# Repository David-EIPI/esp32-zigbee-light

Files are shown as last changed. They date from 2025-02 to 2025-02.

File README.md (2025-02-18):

# esp32-zigbee-light
Remotely controlled indoor light powered by ESP32-H2, integrated with Zigbee and Home Assistant.

## Overview
Building the [stm32-zigbee-light project](https://github.com/David-EIPI/stm32-zigbee-light) left me with several spare PCBs. I decided to repurpose them to experiment with Espressif's Zigbee SDK (zSDK). Overall, zSDK is similar to STM's Z-Stack. Programming with zSDK seems to require slightly fewer API calls, though Z-Stack is somewhat better documented.

## Firmware
The project is written in C and built using `idf.py`. It implements a zero-crossing detector for TRIAC-based dimming and supports the **HLK-LD2420S** mmWave motion sensor with adjustable sensing distance. The firmware exposes 6 endpoints and 11 clusters:

- **6 Analog Output clusters** (configuration)
- **1 Analog Input cluster** (detected presence distance)
- **2 Binary Input clusters** (motion state, light state)
- **1 Multistate Value cluster** (operation mode)
- **1 OnOff cluster** (dimming enable control)

### Motion Sensor
The **HiLink LD2420S** is an **mmWave motion sensor** (not a presence sensor). It is more sensitive than traditional PIR sensors and can estimate the approximate distance to a moving object, in addition to detecting motion.

Communication with the sensor is achieved through a standard text-based UART interface. The sensor can be configured with various parameters such as sensitivity, distance range, scanning frequency, etc. This configuration must be done individually for each sensor using the manufacturer's proprietary software. The serial communication protocol is available on the manufacturer's website, but the documentation is brief and somewhat difficult to interpret.

Rather than configuring the sensor internally, I opted to parse its output. The output contains information about both motion detection and the estimated distance to the detected object. In the firmware, this distance is compared against a configurable threshold to trigger a motion detection event. The threshold is adjustable via Zigbee, providing a practical way to control the sensor's sensitivity.

The sensor is powered through a transistor switch, allowing the firmware to power-cycle it when necessary. I used a **PNP** transistor, which proved to be a suboptimal choice. The sensor draws relatively high current (~50-60mA) and is sensitive to supply voltage. Below **3.2V**, it becomes unstable, and its distance measurements become unreliable. Therefore, the transistor base current needs to be sufficiently high to minimize the voltage drop across it to less than **0.1V**. 
A MOSFET would certainly be a more suitable as a switch here.

## Hardware
I re-used the PCB from the [stm32-zigbee-light](https://github.com/David-EIPI/stm32-zigbee-light) project as the power supply and as the base for the TRIAC dimming circuit. Only a few minor modifications were necessary to integrate the **LD2420S** motion sensor.

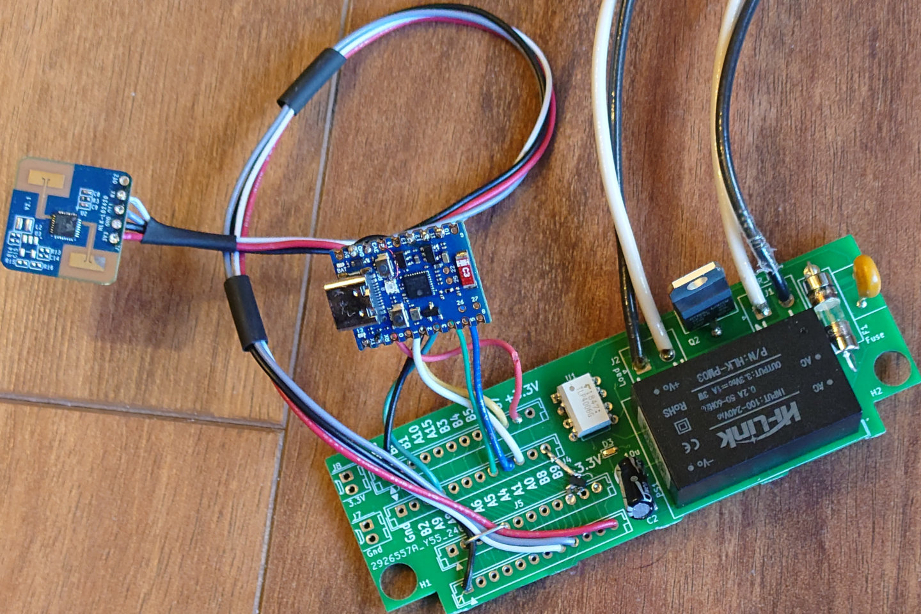
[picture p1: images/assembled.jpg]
The assembled board.
  
Assembled board.

The control board is based on the **ESP32-H2**. I used a small module called the **ESP32-H2 Super Mini**, designed by **Tenstar Robot**. Despite its compact size, the board provides plenty of accessible GPIOs and works well, with **one exception** that I will describe below. This power-on issue is likely to happen in other circuits with a similar power source.

When powered via **USB**, the **ESP32-H2** boots normally. However, when powered from AC mains via the HiLink AC-DC converter, it fails to start. 

I suspect that the HiLink adapter's output capacitor has a high capacitance, leading to a slow output voltage rise **(low slew rate)**, which interferes with the ESP32-H2 startup sequence.

#### Solution:
I added a **4.7µF capacitor** to the **Enable (EN)** pin to delay the startup, which resolved the issue. The module now boots reliably every time. 

Other capacitor values might work as well, but I did not experiment further.

The board is densely packed, leaving little room for additional components. Furthermore, the **EN pin** is not routed to any easily accessible pad. I managed to solder a **0603** capacitor next to the reset button, but to me this was a fairly tricky soldering task.

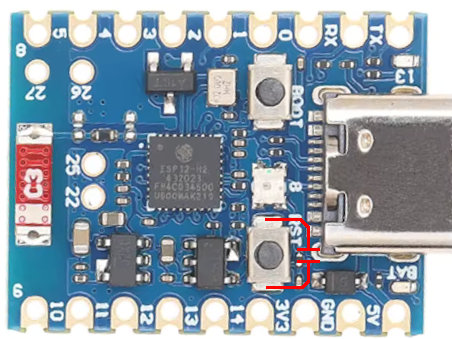
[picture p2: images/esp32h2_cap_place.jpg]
Capacitor placement
  
Capacitor placement is indicated by red lines.

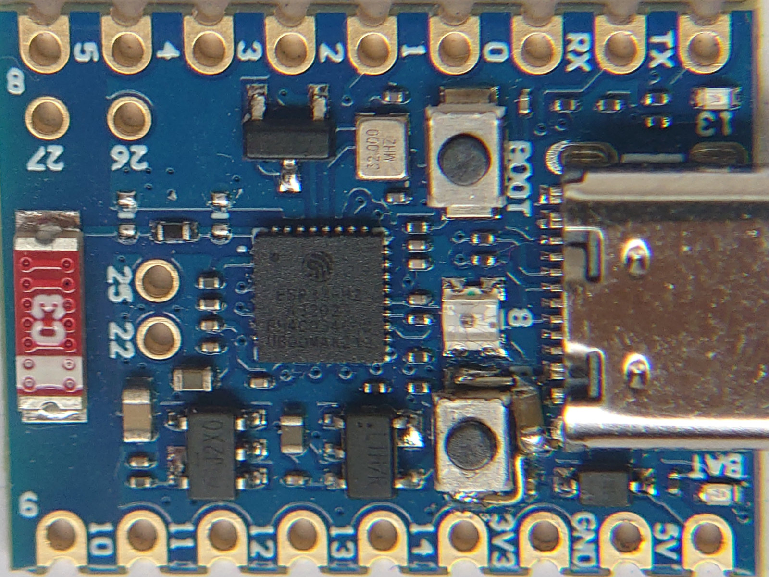
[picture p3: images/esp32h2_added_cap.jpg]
Capacitor photo
  
Photo of the actual board with the added **4.7µF** capacitor.

## ZHA Quirk
As of now, **ZHA (Zigbee Home Automation)** does not fully support several standard Zigbee clusters required for this project, including:

- **Analog Input cluster**
- **Binary Input cluster**
- **Multistate Value cluster**

Additionally, **present_value** atribute of **Multistate Value** cluster is incorrectly defined as **Float32** instead of **uint16** in the underlying **zigpy** library.

Until these clusters are officially supported in the main **ZHA** integration, a custom **quirk** script is required. This quirk file provides proper cluster handling and also extends supported units for the **Analog Input** cluster, adding **microseconds** as a unit. This is useful for the **Phase Correction** setting in the dimming control.

The quirk file should be placed in Home Assistant configuration directory under custom_zha_quirks.
You may need to restart ZHA integration or Home Assistant for the changes to take effect.

The screenshot below shows the device page with custom entity names:

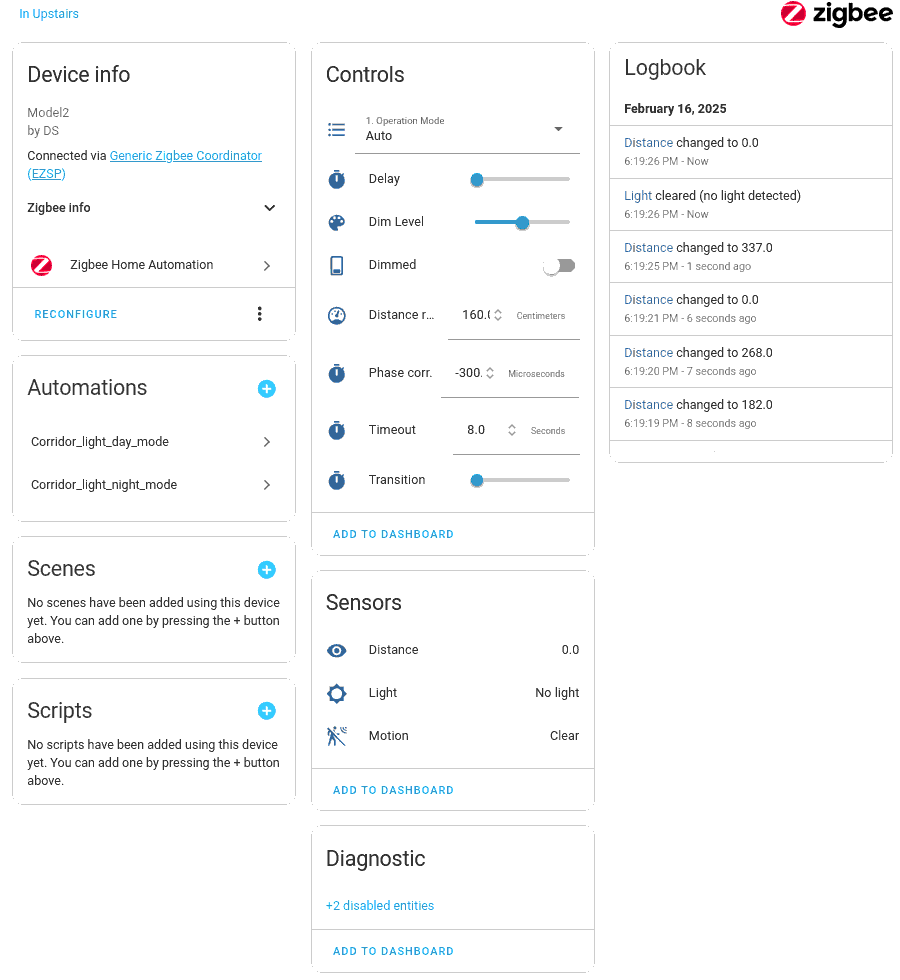
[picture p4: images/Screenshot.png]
Device page
  
ZHA device page in Home Assistant.

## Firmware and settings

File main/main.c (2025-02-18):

/*
 * SPDX-FileCopyrightText: 2021-2024 Espressif Systems (Shanghai) CO LTD
 *
 * SPDX-License-Identifier: CC0-1.0
 *
 * Zigbee HA_on_off_light Example
 *
 * This example code is in the Public Domain (or CC0 licensed, at your option.)
 *
 * Unless required by applicable law or agreed to in writing, this
 * software is distributed on an "AS IS" BASIS, WITHOUT WARRANTIES OR
 * CONDITIONS OF ANY KIND, either express or implied.
 */

#include "freertos/FreeRTOS.h"
#include "freertos/task.h"
#include "esp_check.h"
#include "esp_zigbee_core.h"
#include "esp_log.h"
#include "nvs_flash.h"
#include "ha/esp_zigbee_ha_standard.h"
#include "driver/gpio.h"
#include "main.h"
#include "clock.h"
#include "ld2420_comm.h"
#include "triac_dimmer.h"

#if !defined ZB_ED_ROLE
#error Define ZB_ED_ROLE in idf.py menuconfig to compile light (End Device) source code.
#endif

static const char *TAG = "APP_MAIN";



enum _operation_modes {
    OPMODE_AUTO = 1,
    OPMODE_ON = 2,
    OPMODE_OFF = 3,
};

static uint16_t operation_mode = OPMODE_AUTO;
static bool enable_dimmed_mode = false;
static int prev_motion_detected = 0;
static int light_state = 1, prev_light_state = 0;
static int32_t light_delay = 2; // seconds, delay after motion detection
static int32_t light_timeout = 10; // seconds, time to keep the light on after motion has stopped
static int32_t light_dim_level = DIM_LEVEL_MAX/2;

static uint64_t light_time_on = 0;
static uint64_t no_motion_time = 0;
static gptimer_handle_t timer = 0;
static const uint32_t timer_resolution = 10 * 1000;

static const unsigned indication_led_pin = 13;

TaskHandle_t dimmerTaskHandle = NULL;

/********************* Define functions **************************/
static void bdb_start_top_level_commissioning_cb(uint8_t mode_mask)
{
    ESP_ERROR_CHECK(esp_zb_bdb_start_top_level_commissioning(mode_mask));
}

static const int ZB_INIT_FAIL_COUNT_TO_REBOOT = 60;
static const int ZB_ZDO_FAIL_COUNT_TO_REBOOT = 10;
static int zb_fail_count = 0;


static struct {
    char     description[16];
    float    min_present;
    float    max_present;
    float    present_value;
    float    resolution;
    uint16_t status_flags;
    uint16_t units;
    uint32_t app_type;
    volatile int32_t *value_ptr;
    char     nvs_key[8];
} analog_attr_values[] = {
    {
    .description = "\x07" "Timeout",
    .min_present = 1,
    .max_present = 3600,
    .present_value = 20,
    .resolution = 1,
    .status_flags = 0,
    .units = 73, /* 73 = seconds */
    .app_type = 14 << 16, /* 14 = timer */
//    .value_ptr = &motionTimeout,
    .value_ptr = &light_timeout,
    .nvs_key = "AO_00",
    },

    {
    .description = "\x05" "Delay",
    .min_present = 0,
    .max_present = 20,
    .present_value = 2,
    .resolution = 1,
    .status_flags = 0,
    .units = 73, /* 73 = seconds */
    .app_type = 14 << 16, /* 14 = timer */
    .value_ptr = &light_delay,
    .nvs_key = "AO_01",
    },

    {
    .description = "\x0e" "Distance range",
    .min_present = 1,
    .max_present = 1000,
    .present_value = 200,
    .resolution = 1,
    .status_flags = 0,
    .units = 118, /* 118 = cm */
    .app_type = 2 << 16, /* 2 = Gauge */
    .value_ptr = &motionThreshold,
    .nvs_key = "AO_02",
    },

    {
    .description = "\x09" "Dim level",
    .min_present = 0,
    .max_present = 100,
    .present_value = 50,
    .resolution = 1,
    .status_flags = 0,
    .units = 98, /* 98 = % */
    .app_type = 15 << 16, /* 15 = palette */
    .value_ptr = &light_dim_level,
    .nvs_key = "AO_03",
    },

    {
    .description = "\x0b" "Phase corr.",
    .min_present = -10000,
    .max_present = 10000,
    .present_value = 0,
    .resolution = 1,
    .status_flags = 0,
    .units = 194, /* 194 = microseconds */
    .app_type = 14 << 16, /* 15 = timer */
    .value_ptr = &phaseCorrection_us,
    .nvs_key = "AO_04",
    },

    {
    .description = "\x0a" "Transition",
    .min_present = 0,
    .max_present = 15,
    .present_value = 0,
    .resolution = 1,
    .status_flags = 0,
    .units = 95,
    .app_type = 14 << 16, /* 15 = timer */
    .value_ptr = &transitionTime,
    .nvs_key = "AO_05",
    },


};



static struct {
    char     *states_text;
    char     description[16];
    uint16_t *present_value_ptr;
    uint16_t status_flags;
    uint16_t number_of_states;
    char     nvs_key[8];
} multistate_attr_values[] = {
    {

/* Binary format for the ZCL string array: 1. type; 2. count; 3. array of strings.
*/
    .states_text = "\x42"       /*ESP_ZB_ZCL_ATTR_TYPE_CHAR_STRING = 0x42 */
                    "\x04\x00"  /* Element count */
                    "\x04" "Auto"
                    "\x02" "On"
                    "\x03" "Off",
    .description = "\x0e" "Operation mode",
    .present_value_ptr = &operation_mode,
    .status_flags = 0,
    .number_of_states = 3,
    .nvs_key = "MV_00",
    }
};

char light_on_binary_desc[] = "\x0b" "Light is on";
char motion_binary_desc[] = "\x0f" "Motion detected";

const char ZB_STORAGE_NAMESPACE[] = "zb_storage";

static void init_gpio(void)
{
    const gpio_config_t io_conf = {
        .intr_type = GPIO_INTR_DISABLE,
        .mode = GPIO_MODE_OUTPUT,
        .pin_bit_mask = (1ULL << indication_led_pin),
        .pull_down_en = 0,
        .pull_up_en = 0,
    };

    gpio_config(&io_conf);
    gpio_set_level(indication_led_pin, 1);
}

/* Signal the dimmer task to disable its sync source and stop the timer
    to avoid light flash when the source pin is disabled at restart. */
static void stop_dimmer_and_restart(void)
{
    stopDimmer = 1;
    vTaskDelay(pdMS_TO_TICKS(200));
    esp_restart();
}


void esp_zb_app_signal_handler(esp_zb_app_signal_t *signal_struct)
{
    uint32_t *p_sg_p       = signal_struct->p_app_signal;
    esp_err_t err_status = signal_struct->esp_err_status;
    esp_zb_app_signal_type_t sig_type = *p_sg_p;
    uint8_t min_lqi;

    switch (sig_type) {
    case ESP_ZB_NLME_STATUS_INDICATION:
        ESP_LOGI(TAG, "%s, status: 0x%x\n", esp_zb_zdo_signal_to_string(sig_type), *(uint8_t *)esp_zb_app_signal_get_params(p_sg_p));
        break;
    case ESP_ZB_ZDO_SIGNAL_SKIP_STARTUP:
        ESP_LOGI(TAG, "Zigbee stack initialized");
        esp_zb_bdb_start_top_level_commissioning(ESP_ZB_BDB_MODE_INITIALIZATION);
        min_lqi = esp_zb_secur_network_min_join_lqi_get();
        ESP_LOGI(TAG, "Min LQI = %u", (unsigned)min_lqi);
        esp_zb_secur_network_min_join_lqi_set(0);
        break;
    case ESP_ZB_BDB_SIGNAL_DEVICE_FIRST_START:
    case ESP_ZB_BDB_SIGNAL_DEVICE_REBOOT:
        if (err_status == ESP_OK) {
            ESP_LOGI(TAG, "Device started up in %s factory-reset mode", esp_zb_bdb_is_factory_new() ? "" : "non");
            if (esp_zb_bdb_is_factory_new()) {
                ESP_LOGI(TAG, "Start network steering");
                esp_zb_bdb_start_top_level_commissioning(ESP_ZB_BDB_MODE_NETWORK_STEERING);
            } else {
                ESP_LOGI(TAG, "Device rebooted");
            }

            zb_fail_count = 0;
        } else {
            /* commissioning failed */

            if (ZB_INIT_FAIL_COUNT_TO_REBOOT <= zb_fail_count) {
                ESP_LOGI(TAG, "ZB init has failed too many times. Restarting.");
                stop_dimmer_and_restart();
                break;
            }

            ESP_LOGW(TAG, "Failed to initialize Zigbee stack (status: %s)", esp_err_to_name(err_status));
            esp_zb_scheduler_alarm((esp_zb_callback_t)bdb_start_top_level_commissioning_cb, ESP_ZB_BDB_MODE_INITIALIZATION, 1000);
            zb_fail_count += 1;
        }
        break;
    case ESP_ZB_BDB_SIGNAL_STEERING:
        if (err_status == ESP_OK) {
            esp_zb_ieee_addr_t extended_pan_id;
            esp_zb_get_extended_pan_id(extended_pan_id);
            ESP_LOGI(TAG, "Joined network successfully (Extended PAN ID: %02x:%02x:%02x:%02x:%02x:%02x:%02x:%02x, PAN ID: 0x%04hx, Channel:%d, Short Address: 0x%04hx)",
                     extended_pan_id[7], extended_pan_id[6], extended_pan_id[5], extended_pan_id[4],
                     extended_pan_id[3], extended_pan_id[2], extended_pan_id[1], extended_pan_id[0],
                     esp_zb_get_pan_id(), esp_zb_get_current_channel(), esp_zb_get_short_address());
        } else {
            ESP_LOGI(TAG, "Network steering was not successful (status: %s)", esp_err_to_name(err_status));
            esp_zb_scheduler_alarm((esp_zb_callback_t)bdb_start_top_level_commissioning_cb, ESP_ZB_BDB_MODE_NETWORK_STEERING, 1000);
        }
        break;
    case ESP_ZB_ZDO_SIGNAL_LEAVE:
        ESP_LOGI(TAG, "Leave and network steering initiated.");
        esp_zb_factory_reset();
        esp_zb_scheduler_alarm((esp_zb_callback_t)bdb_start_top_level_commissioning_cb, ESP_ZB_BDB_MODE_NETWORK_STEERING, 1000);
        break;
    case ESP_ZB_ZDO_DEVICE_UNAVAILABLE:
        if (ZB_ZDO_FAIL_COUNT_TO_REBOOT <= zb_fail_count) {
            ESP_LOGI(TAG, "ZDO device unavailable. Restarting.");
            stop_dimmer_and_restart();
            break;
        }
        zb_fail_count += 1;
        __attribute__ ((fallthrough));
    default:
        ESP_LOGI(TAG, "ZDO signal: %s (0x%x), status: %s", esp_zb_zdo_signal_to_string(sig_type), sig_type,
                 esp_err_to_name(err_status));
        break;
    }
}

static struct {
    char     description[16];
    float    min_present;
    float    max_present;
    float    present_value;
    float    resolution;
    uint16_t status_flags;
    uint16_t units;
    uint32_t app_type;
} distance_sensor_attr_values = {
    .description = DISTANCE_SENSOR_DESC,
    .min_present = 0,
    .max_present = 1000,
    .present_value = 0,
    .resolution = 1,
    .status_flags = 0,
    .units = 118, /* 118 = cm */
    .app_type = 2 << 16, /* 2 = Gauge icon */
};

static struct {
    int id;
    void *ptr;
    int access;
} distance_sensor_attr_data[] = {
    { ESP_ZB_ZCL_ATTR_ANALOG_INPUT_DESCRIPTION_ID      , &distance_sensor_attr_values.description,   .access = ESP_ZB_ZCL_ATTR_ACCESS_READ_ONLY },
    { ESP_ZB_ZCL_ATTR_ANALOG_INPUT_MAX_PRESENT_VALUE_ID, &distance_sensor_attr_values.max_present,   .access = ESP_ZB_ZCL_ATTR_ACCESS_READ_ONLY },
    { ESP_ZB_ZCL_ATTR_ANALOG_INPUT_MIN_PRESENT_VALUE_ID, &distance_sensor_attr_values.min_present,   .access = ESP_ZB_ZCL_ATTR_ACCESS_READ_ONLY },
    { ESP_ZB_ZCL_ATTR_ANALOG_INPUT_PRESENT_VALUE_ID    , &distance_sensor_attr_values.present_value, .access = ESP_ZB_ZCL_ATTR_ACCESS_READ_WRITE | ESP_ZB_ZCL_ATTR_ACCESS_REPORTING },
    { ESP_ZB_ZCL_ATTR_ANALOG_INPUT_RESOLUTION_ID       , &distance_sensor_attr_values.resolution,    .access = ESP_ZB_ZCL_ATTR_ACCESS_READ_ONLY },
    { ESP_ZB_ZCL_ATTR_ANALOG_INPUT_STATUS_FLAGS_ID     , &distance_sensor_attr_values.status_flags,  .access = ESP_ZB_ZCL_ATTR_ACCESS_READ_WRITE },
    { ESP_ZB_ZCL_ATTR_ANALOG_INPUT_ENGINEERING_UNITS_ID, &distance_sensor_attr_values.units,         .access = ESP_ZB_ZCL_ATTR_ACCESS_READ_ONLY },
    { ESP_ZB_ZCL_ATTR_ANALOG_INPUT_APPLICATION_TYPE_ID , &distance_sensor_attr_values.app_type,      .access = ESP_ZB_ZCL_ATTR_ACCESS_READ_ONLY }
};

static  esp_zb_zcl_reporting_info_t reporting_info = {
        .direction = ESP_ZB_ZCL_CMD_DIRECTION_TO_SRV,
        .ep = 0, //HA_ANALOG_INPUT_ENDPOINT,
        .cluster_id = ESP_ZB_ZCL_CLUSTER_ID_ANALOG_INPUT,
        .cluster_role = ESP_ZB_ZCL_CLUSTER_SERVER_ROLE,
        .dst.profile_id = ESP_ZB_AF_HA_PROFILE_ID,
        .u.send_info.min_interval = 0,
        .u.send_info.max_interval = 10,
        .u.send_info.def_min_interval = 0,
        .u.send_info.def_max_interval = 10,
        .u.send_info.delta.u16 = 1,
        .attr_id = ESP_ZB_ZCL_ATTR_ANALOG_INPUT_PRESENT_VALUE_ID,
        .manuf_code = ESP_ZB_ZCL_ATTR_NON_MANUFACTURER_SPECIFIC,
    };


#define MULTISTATE_ATTR_FIELD_OFFSET(field) (offsetof(typeof(multistate_attr_values[0]), field))

static struct {
    int id;
    int offs;
    int access;
} multistate_attr_offset[] = {
    { ESP_ZB_ZCL_ATTR_MULTI_VALUE_DESCRIPTION_ID      , MULTISTATE_ATTR_FIELD_OFFSET(description),   .access = ESP_ZB_ZCL_ATTR_ACCESS_READ_ONLY },
//    { ESP_ZB_ZCL_ATTR_MULTI_VALUE_PRESENT_VALUE_ID    , MULTISTATE_ATTR_FIELD_OFFSET(present_value), .access = ESP_ZB_ZCL_ATTR_ACCESS_READ_WRITE | ESP_ZB_ZCL_ATTR_ACCESS_REPORTING },
    { ESP_ZB_ZCL_ATTR_MULTI_VALUE_STATUS_FLAGS_ID     , MULTISTATE_ATTR_FIELD_OFFSET(status_flags),  .access = ESP_ZB_ZCL_ATTR_ACCESS_READ_WRITE },
/* States text attribute is not supported... */
};

static esp_err_t nvs_save_int_attribute(int32_t value, const char *key)
{
    nvs_handle_t handle = 0;
    esp_err_t err = ESP_OK;

//    ESP_LOGI(TAG, "Saving attribute: %s = %ld", key, value);
    ESP_RETURN_ON_ERROR(nvs_open(ZB_STORAGE_NAMESPACE, NVS_READWRITE, &handle), TAG, "Error opening NVS handle!");

    err = nvs_set_i32(handle, key, value);
    if (err != ESP_OK)
    {
        ESP_LOGE(TAG, "Failed to write to NVS (%s)!", esp_err_to_name(err));

    } else {

        err = nvs_commit(handle);
        if (err != ESP_OK)
        {
            ESP_LOGE(TAG, "Failed to commit to NVS (%s)!", esp_err_to_name(err));
        }
    }

    nvs_close(handle);
    return err;
}

static esp_zb_attribute_list_t *create_multistate_cluster(nvs_handle_t handle)
{
    esp_zb_attribute_list_t *esp_zb_multi_cluster = esp_zb_zcl_attr_list_create(ESP_ZB_ZCL_CLUSTER_ID_MULTI_VALUE);

    if (esp_zb_multi_cluster != NULL) {
/* Assemble the cluster from the attributes one by one, because the helper function (esp_zb_multistate_value_cluster_create)
    does not set ACCESS_REPORTING flag on "present_value" attribute.
*/
        int i;
        for (i = 0; i < lengthof(multistate_attr_offset); i++) {
	    esp_zb_multistate_value_cluster_add_attr(esp_zb_multi_cluster, multistate_attr_offset[i].id,
	        ((void*)&multistate_attr_values[0]) + multistate_attr_offset[i].offs );
        }

/*  Attempt to find a saved attribute value */
        int32_t saved_value = 0;
        if (handle && ESP_OK == nvs_get_i32(handle, multistate_attr_values[0].nvs_key, &saved_value)) {
            ESP_LOGI(TAG, "Loaded attribute: %s = %ld", multistate_attr_values[0].nvs_key, saved_value);

/* Do not start up in disabled state */
            if (saved_value == OPMODE_OFF || saved_value > multistate_attr_values[0].number_of_states)
                saved_value = OPMODE_AUTO;

            *multistate_attr_values[0].present_value_ptr = saved_value;
        }

        esp_zb_cluster_add_attr(esp_zb_multi_cluster,
	    ESP_ZB_ZCL_CLUSTER_ID_MULTI_VALUE,
	    ESP_ZB_ZCL_ATTR_MULTI_VALUE_PRESENT_VALUE_ID,
	    ESP_ZB_ZCL_ATTR_TYPE_U16,
	    ESP_ZB_ZCL_ATTR_ACCESS_READ_WRITE | ESP_ZB_ZCL_ATTR_ACCESS_REPORTING,
	    multistate_attr_values[0].present_value_ptr);

    }

    ESP_LOGI(TAG, "Multistate cluster created: %d", (int)(esp_zb_multi_cluster!=NULL));
    return esp_zb_multi_cluster;
}

#define ANALOG_ATTR_FIELD_OFFSET(field) (offsetof(typeof(analog_attr_values[0]), field))

static struct {
    int id;
    int offs;
    int access;
} analog_attr_offset[] = {
    { ESP_ZB_ZCL_ATTR_ANALOG_OUTPUT_DESCRIPTION_ID      , ANALOG_ATTR_FIELD_OFFSET(description),   .access = ESP_ZB_ZCL_ATTR_ACCESS_READ_ONLY },
    { ESP_ZB_ZCL_ATTR_ANALOG_OUTPUT_MAX_PRESENT_VALUE_ID, ANALOG_ATTR_FIELD_OFFSET(max_present),   .access = ESP_ZB_ZCL_ATTR_ACCESS_READ_ONLY },
    { ESP_ZB_ZCL_ATTR_ANALOG_OUTPUT_MIN_PRESENT_VALUE_ID, ANALOG_ATTR_FIELD_OFFSET(min_present),   .access = ESP_ZB_ZCL_ATTR_ACCESS_READ_ONLY },
    { ESP_ZB_ZCL_ATTR_ANALOG_OUTPUT_PRESENT_VALUE_ID    , ANALOG_ATTR_FIELD_OFFSET(present_value), .access = ESP_ZB_ZCL_ATTR_ACCESS_READ_WRITE | ESP_ZB_ZCL_ATTR_ACCESS_REPORTING },
    { ESP_ZB_ZCL_ATTR_ANALOG_OUTPUT_RESOLUTION_ID       , ANALOG_ATTR_FIELD_OFFSET(resolution),    .access = ESP_ZB_ZCL_ATTR_ACCESS_READ_ONLY },
    { ESP_ZB_ZCL_ATTR_ANALOG_OUTPUT_STATUS_FLAGS_ID     , ANALOG_ATTR_FIELD_OFFSET(status_flags),  .access = ESP_ZB_ZCL_ATTR_ACCESS_READ_WRITE },
    { ESP_ZB_ZCL_ATTR_ANALOG_OUTPUT_ENGINEERING_UNITS_ID, ANALOG_ATTR_FIELD_OFFSET(units),         .access = ESP_ZB_ZCL_ATTR_ACCESS_READ_ONLY },
    { ESP_ZB_ZCL_ATTR_ANALOG_OUTPUT_APPLICATION_TYPE_ID , ANALOG_ATTR_FIELD_OFFSET(app_type),      .access = ESP_ZB_ZCL_ATTR_ACCESS_READ_ONLY }
};

/* Setup AnalogOutput clusters and add them to the endpoints starting from the provided index. */
static esp_zb_attribute_list_t * create_analog_cluster(unsigned idx, nvs_handle_t handle)
{
    esp_zb_attribute_list_t *esp_zb_analog_cluster = esp_zb_zcl_attr_list_create(ESP_ZB_ZCL_CLUSTER_ID_ANALOG_OUTPUT);
    int nattrs = 0;
    if (esp_zb_analog_cluster != NULL) {

/*  Attempt to find a saved attribute value */
        int32_t saved_value = 0;
        if (handle && ESP_OK == nvs_get_i32(handle, analog_attr_values[idx].nvs_key, &saved_value)) {
            *analog_attr_values[idx].value_ptr = saved_value;
            ESP_LOGI(TAG, "Loaded attribute: %s = %ld", analog_attr_values[idx].nvs_key, saved_value);
        }
        analog_attr_values[idx].present_value = *analog_attr_values[idx].value_ptr;

        int i;
        for (i = 0; i < lengthof(analog_attr_offset); i++) {
	    esp_err_t err = esp_zb_analog_output_cluster_add_attr(esp_zb_analog_cluster, analog_attr_offset[i].id,
	        ((void*)&analog_attr_values[idx]) + analog_attr_offset[i].offs );
	    if (ESP_OK == err)
	        nattrs += 1;
        }
    }

    ESP_LOGI(TAG, "Analog cluster %u created. Attrs: %d", idx, nattrs);
    return esp_zb_analog_cluster;
}

/* Setup AnalogInput cluster */
static esp_zb_attribute_list_t * create_analog_input_cluster(void)
{
    esp_zb_attribute_list_t *esp_zb_analog_input_cluster = esp_zb_zcl_attr_list_create(ESP_ZB_ZCL_CLUSTER_ID_ANALOG_INPUT);
    int i;
    for (i = 0; i < sizeof(distance_sensor_attr_data) / sizeof(distance_sensor_attr_data[0]); i++) {
	esp_zb_analog_input_cluster_add_attr(esp_zb_analog_input_cluster, distance_sensor_attr_data[i].id, distance_sensor_attr_data[i].ptr);
    }

    return esp_zb_analog_input_cluster;
}

/* Setup OnOff switch cluster */
static esp_zb_attribute_list_t * create_on_off_cluster(nvs_handle_t handle)
{

    esp_zb_on_off_cluster_cfg_t on_off_cfg = { .on_off = false };

    esp_zb_attribute_list_t *on_off_cluster = esp_zb_on_off_cluster_create(&on_off_cfg);

    return on_off_cluster;
}


static esp_zb_attribute_list_t * create_binary_input_cluster(char *desc, int value)
{
    esp_zb_binary_input_cluster_cfg_t cfg = { false, 0 };
    esp_zb_attribute_list_t * binary_input_cluster = esp_zb_binary_input_cluster_create(&cfg);
    if (desc) {
        ESP_ERROR_CHECK(esp_zb_binary_input_cluster_add_attr(
            binary_input_cluster,
            ESP_ZB_ZCL_ATTR_BINARY_INPUT_DESCRIPTION_ID,
            desc
        ));
    }
    ESP_ERROR_CHECK(esp_zb_cluster_add_attr(binary_input_cluster,
	    ESP_ZB_ZCL_CLUSTER_ID_BINARY_INPUT,
	    ESP_ZB_ZCL_ATTR_BINARY_INPUT_PRESENT_VALUE_ID,
	    ESP_ZB_ZCL_ATTR_TYPE_BOOL,
	    ESP_ZB_ZCL_ATTR_ACCESS_READ_WRITE | ESP_ZB_ZCL_ATTR_ACCESS_REPORTING,
	    &value));

    return binary_input_cluster;
}

/* Setup Basic cluster */
static esp_zb_attribute_list_t * create_basic_cluster(char *manufacturer)
{
    uint8_t zero = 0;
    uint8_t version = 3;

    esp_zb_attribute_list_t *esp_zb_basic_cluster = esp_zb_zcl_attr_list_create(ESP_ZB_ZCL_CLUSTER_ID_BASIC);

    if (esp_zb_basic_cluster != NULL) {
        esp_zb_basic_cluster_add_attr(esp_zb_basic_cluster, ESP_ZB_ZCL_ATTR_BASIC_MANUFACTURER_NAME_ID, manufacturer);
        esp_zb_basic_cluster_add_attr(esp_zb_basic_cluster, ESP_ZB_ZCL_ATTR_BASIC_MODEL_IDENTIFIER_ID, MODEL_IDENTIFIER);
        esp_zb_basic_cluster_add_attr(esp_zb_basic_cluster, ESP_ZB_ZCL_ATTR_BASIC_ZCL_VERSION_ID, &version);
        esp_zb_basic_cluster_add_attr(esp_zb_basic_cluster, ESP_ZB_ZCL_ATTR_BASIC_POWER_SOURCE_ID, &zero);
    }
    return esp_zb_basic_cluster;
}

static void setup_reporting(void)
{
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
void app_main(void)
{
    init_gpio();

    esp_zb_platform_config_t config = {
        .radio_config = ESP_ZB_DEFAULT_RADIO_CONFIG(),
        .host_config = ESP_ZB_DEFAULT_HOST_CONFIG(),
    };
    ESP_ERROR_CHECK(nvs_flash_init());
    ESP_ERROR_CHECK(esp_zb_platform_config(&config));
    light_driver_init(LIGHT_DEFAULT_OFF);
    init_timer(&timer, timer_resolution);

    xTaskCreate(esp_zb_task, "Zigbee_main", 1024*8, NULL, 5, NULL);
    xTaskCreate(ld2420_task, "uart_rx_task", 1024 * 4, NULL, configMAX_PRIORITIES - 1, NULL);
    xTaskCreate(triac_dimmer_task, "dimmer_task", 1024 * 4, NULL, configMAX_PRIORITIES - 1, &dimmerTaskHandle);

    gpio_set_level(indication_led_pin, 0);

    if (ESP_RST_SW == esp_reset_reason()) /* Do not turn the light on after soft reset */
        light_state = 0;

    light_control_task(NULL);
}

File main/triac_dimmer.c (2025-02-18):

#include "freertos/FreeRTOS.h"
#include "freertos/task.h"
#include "driver/gpio.h"
#include "esp_check.h"
#include "esp_err.h"
#include "esp_system.h"
#include "driver/mcpwm_prelude.h"
#include "driver/mcpwm_cap.h"
#include "triac_dimmer.h"

#define TRIAC_CONTROL_PIN (GPIO_NUM_10)
#define AC_SYNC_PIN       (GPIO_NUM_11)


volatile int32_t dimLevel = DIM_LEVEL_MAX / 2;
volatile int32_t phaseCorrection_us = -300;
volatile int32_t transitionTime = 0;
volatile int stopDimmer = 1;

static uint32_t ac_wave_period = 0;
static uint32_t ac_pulse_width = 0;

static uint32_t cap_timer_resolution = 0;

/* MCPWM timer is 16 bit, and at 6MHz it can provide up to 1/90 s PWM cycle length.
 With AC 60Hz we need PWM cycle length 1/120 s.
 Also 6MHz is an integer divider for APB clock of 48HZ */
static const uint32_t mcpwm_timer_resolution = 6 * 1000 * 1000;
static const uint32_t mcpwm_60Hz_half_period = mcpwm_timer_resolution / 60 / 2;


const static char *CTAG = "capture";
const static char *GTAG = "generator";

/* Capture timer */

static bool ac_wave_detect_callback(mcpwm_cap_channel_handle_t cap_chan, const mcpwm_capture_event_data_t *edata, void *user_data)
{
    static uint32_t prev_pos_edge = 0;
    TaskHandle_t task_to_notify = (TaskHandle_t)user_data;
    BaseType_t high_task_wakeup = pdFALSE;

    if (edata->cap_edge == MCPWM_CAP_EDGE_POS) {
        ac_wave_period = edata->cap_value - prev_pos_edge;

        /* store the timestamp when pos edge is detected */
        prev_pos_edge = edata->cap_value;
    } else {
       /* pulse length that marks the top of the sine wave */
        ac_pulse_width = edata->cap_value - prev_pos_edge;
        /* Notify the task about the detected pulse to update the dimmer settings */
        xTaskNotifyFromISR(task_to_notify, ac_pulse_width, eSetValueWithOverwrite, &high_task_wakeup);
    }

    return high_task_wakeup == pdTRUE;
}

void setup_capture(void)
{

    ESP_LOGI(CTAG, "Install capture timer");
    mcpwm_cap_timer_handle_t cap_timer = NULL;
    mcpwm_capture_timer_config_t cap_conf = {
        .clk_src = MCPWM_CAPTURE_CLK_SRC_DEFAULT,
        .group_id = 0,
    };
    ESP_ERROR_CHECK(mcpwm_new_capture_timer(&cap_conf, &cap_timer));

    ESP_LOGI(CTAG, "Install capture channel");
    mcpwm_cap_channel_handle_t cap_chan = NULL;
    mcpwm_capture_channel_config_t cap_ch_conf = {
        .gpio_num = AC_SYNC_PIN,
        .prescale = 1,
        // capture on both edges
        .flags.neg_edge = true,
        .flags.pos_edge = true,
        // pull up internally
        .flags.pull_up = true,
    };
    ESP_ERROR_CHECK(mcpwm_new_capture_channel(cap_timer, &cap_ch_conf, &cap_chan));

    ESP_LOGI(CTAG, "Register capture callback");
    TaskHandle_t cur_task = xTaskGetCurrentTaskHandle();
    mcpwm_capture_event_callbacks_t cbs = {
        .on_cap = ac_wave_detect_callback,
    };
    ESP_ERROR_CHECK(mcpwm_capture_channel_register_event_callbacks(cap_chan, &cbs, cur_task));

    ESP_LOGI(CTAG, "Enable capture channel");
    ESP_ERROR_CHECK(mcpwm_capture_channel_enable(cap_chan));

    ESP_LOGI(CTAG, "Configure Trig pin");
    gpio_config_t io_conf = {
        .mode = GPIO_MODE_OUTPUT,
        .pin_bit_mask = 1ULL << TRIAC_CONTROL_PIN,
    };
    ESP_ERROR_CHECK(gpio_config(&io_conf));
    // drive low by default
    ESP_ERROR_CHECK(gpio_set_level(TRIAC_CONTROL_PIN, 0));

    ESP_LOGI(CTAG, "Enable and start capture timer");
    ESP_ERROR_CHECK(mcpwm_capture_timer_enable(cap_timer));
    ESP_ERROR_CHECK(mcpwm_capture_timer_start(cap_timer));

    ESP_ERROR_CHECK(mcpwm_capture_timer_get_resolution(cap_timer, &cap_timer_resolution));
}

/* Setup MCPWM Generator  */

static mcpwm_timer_handle_t gen_timer = NULL;
static mcpwm_sync_handle_t gpio_sync_source = NULL;
static mcpwm_cmpr_handle_t comparator = NULL;

static void set_pwm_timer_phase(uint32_t phase_ticks)
{
    mcpwm_timer_sync_phase_config_t sync_phase_config = {
        .count_value = phase_ticks,
        .direction = MCPWM_TIMER_DIRECTION_UP,
        .sync_src = gpio_sync_source,
    };

    ESP_ERROR_CHECK(mcpwm_timer_set_phase_on_sync(gen_timer, &sync_phase_config));
}

static void setup_generator(void)
{
    ESP_LOGI(GTAG, "Create generator timer");
    mcpwm_timer_config_t timer_config = {
        .clk_src = MCPWM_TIMER_CLK_SRC_DEFAULT,
        .group_id = 0,
        .resolution_hz = mcpwm_timer_resolution,
        .period_ticks = mcpwm_60Hz_half_period, /* Preliminary setting, will be adjusted from the capture timer */
        .count_mode = MCPWM_TIMER_COUNT_MODE_UP,
    };

    ESP_ERROR_CHECK(mcpwm_new_timer(&timer_config, &gen_timer));

    ESP_LOGI(GTAG, "Create operator");
    mcpwm_oper_handle_t gen_operator;
    mcpwm_operator_config_t operator_config = {
        .group_id = 0, // operator should be in the same group of the above timers
    };

    ESP_ERROR_CHECK(mcpwm_new_operator(&operator_config, &gen_operator));


    ESP_LOGI(GTAG, "Connect timer and operator with each other");
    ESP_ERROR_CHECK(mcpwm_operator_connect_timer(gen_operator, gen_timer));

    ESP_LOGI(GTAG, "Create comparator");
    mcpwm_comparator_config_t compare_config = {
        .flags.update_cmp_on_tez = true,
    };

    ESP_ERROR_CHECK(mcpwm_new_comparator(gen_operator, &compare_config, &comparator));
        // init compare for each comparator
    ESP_ERROR_CHECK(mcpwm_comparator_set_compare_value(comparator, timer_config.period_ticks)); // start with 100% duty

    ESP_LOGI(GTAG, "Create generators");
    mcpwm_gen_handle_t generator;
    mcpwm_generator_config_t gen_config = {
        .gen_gpio_num = TRIAC_CONTROL_PIN,
    };
    ESP_ERROR_CHECK(mcpwm_new_generator(gen_operator, &gen_config, &generator));

    ESP_LOGI(GTAG, "Set generator actions on timer and compare event");

    ESP_ERROR_CHECK(mcpwm_generator_set_action_on_timer_event(generator,
        // when the timer value is zero, and is counting up, set output to high
            MCPWM_GEN_TIMER_EVENT_ACTION(MCPWM_TIMER_DIRECTION_UP, MCPWM_TIMER_EVENT_EMPTY, MCPWM_GEN_ACTION_HIGH)));

    ESP_ERROR_CHECK(mcpwm_generator_set_action_on_compare_event(generator,
        // when compare event happens, and timer is counting up, set output to low
            MCPWM_GEN_COMPARE_EVENT_ACTION(MCPWM_TIMER_DIRECTION_UP, comparator, MCPWM_GEN_ACTION_LOW)));


    ESP_LOGI(GTAG, "Start generator timer");
    ESP_ERROR_CHECK(mcpwm_timer_enable(gen_timer));
    ESP_ERROR_CHECK(mcpwm_timer_start_stop(gen_timer, MCPWM_TIMER_START_NO_STOP));


    ESP_LOGI(GTAG, "Create GPIO sync source");
    mcpwm_gpio_sync_src_config_t gpio_sync_config = {
        .group_id = 0,  // GPIO fault should be in the same group of the above timers
        .gpio_num = AC_SYNC_PIN,
        .flags.pull_up = true,
        .flags.active_neg = false,  // by default, a posedge pulse can trigger a sync event
    };

    ESP_ERROR_CHECK(mcpwm_new_gpio_sync_src(&gpio_sync_config, &gpio_sync_source));
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
